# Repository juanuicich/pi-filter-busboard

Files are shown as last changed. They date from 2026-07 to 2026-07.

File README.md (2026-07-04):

# Low-Noise Eurorack Busboard (37cm)

An open-source, high-integrity power distribution busboard for Eurorack modular synthesizer systems. It features aggressive passive filtering designed specifically to clean up the switching and regulation ripple from standard industrial switched-mode power supplies (such as the Mean Well LRS-75-12).

## Features

- **37cm Long Layout:** Optimized for physical accessibility across 84hp cases without needing to uninstall central modules to change power cables.
- **Third-Order CLC Pi-Filter:** Achieves ~35dB of noise attenuation at 1kHz, eliminating audible regulation ripple and high-frequency switching hash (65kHz+).
- **Optional +5V Sub-System:** Includes an unpopulated TO-220 footprint compatible with high-efficiency switching buck regulators (e.g., Murata OKI-78SR-5) to drive 5V-enabled IDC headers locally.
- **LED Rail Indicators:** Post-filter diagnostic LEDs immediately confirm active voltage delivery to the distribution rail.

## Filter & Power Specifications

- **Input Terminals:** 3-pin screw terminal block (5.08mm pitch, Phoenix Contact standard).
- **Maximum Current Load:** 2A - 2.5A continuous per board.
- **Input Capacitors ($C_{in}$):** 220µF / 25V+ Low-ESR Electrolytic ($\le$ 0.1Ω impedance at 100kHz).
- **Series Inductors ($L$):** 330µH Toroidal Chokes ($\ge$ 3A rated, low DCR).
- **Output Capacitors ($C_{out}$):** 4700µF / 25V Low-ESR Electrolytic ($\le$ 0.03Ω impedance at 100kHz).

## Critical Assembly & Solder Notes

⚠️ **WARNING: REVERSE POLARITY HAZARD**
Electrolytic capacitors are polarized. On the **-12V rail**, Ground (0V) is the more positive potential. You **MUST** solder the positive lead (+) of the -12V capacitors directly to the Ground plane, and the negative lead (-) to the -12V trace. Installing them backward will cause the capacitors to burst violently upon power-up.

- **Thermal Reliefs:** Ensure your KiCad zone properties retain thermal relief spokes for through-hole pads, otherwise the massive output capacitors and ground planes will sink all the heat from your soldering iron.
- **Mechanical Security:** Because the 4700µF output capacitors carry significant mass, it is recommended to apply a small dab of non-conductive electronics-grade silicone or hot glue between the base of the capacitor capacitor body and the PCB after soldering to relieve trace stress during case transit.

## License

This project is open-source hardware. Feel free to modify, build, or manufacture your own variants.

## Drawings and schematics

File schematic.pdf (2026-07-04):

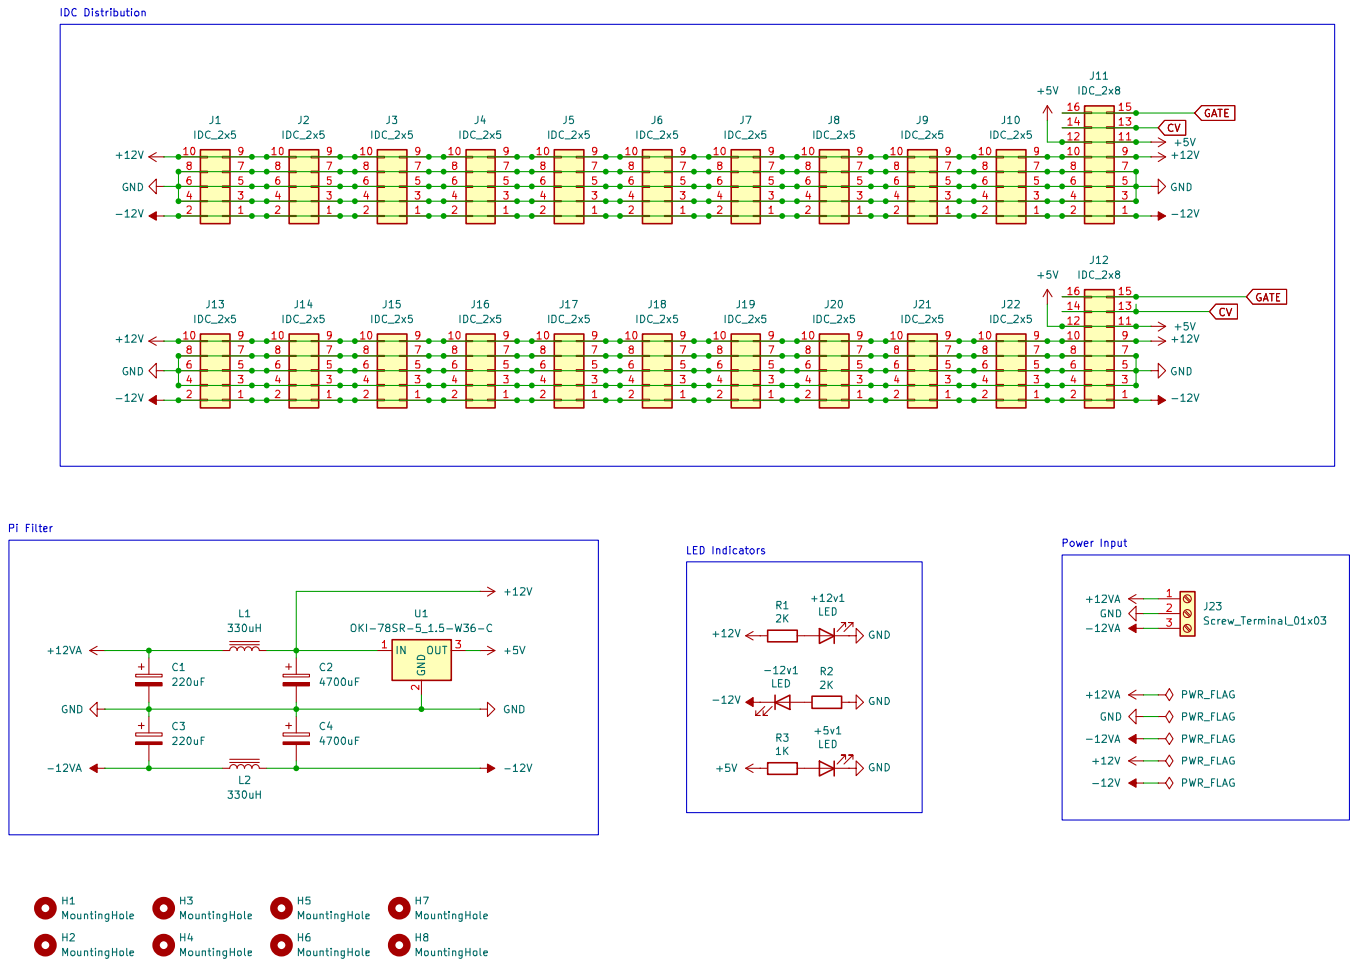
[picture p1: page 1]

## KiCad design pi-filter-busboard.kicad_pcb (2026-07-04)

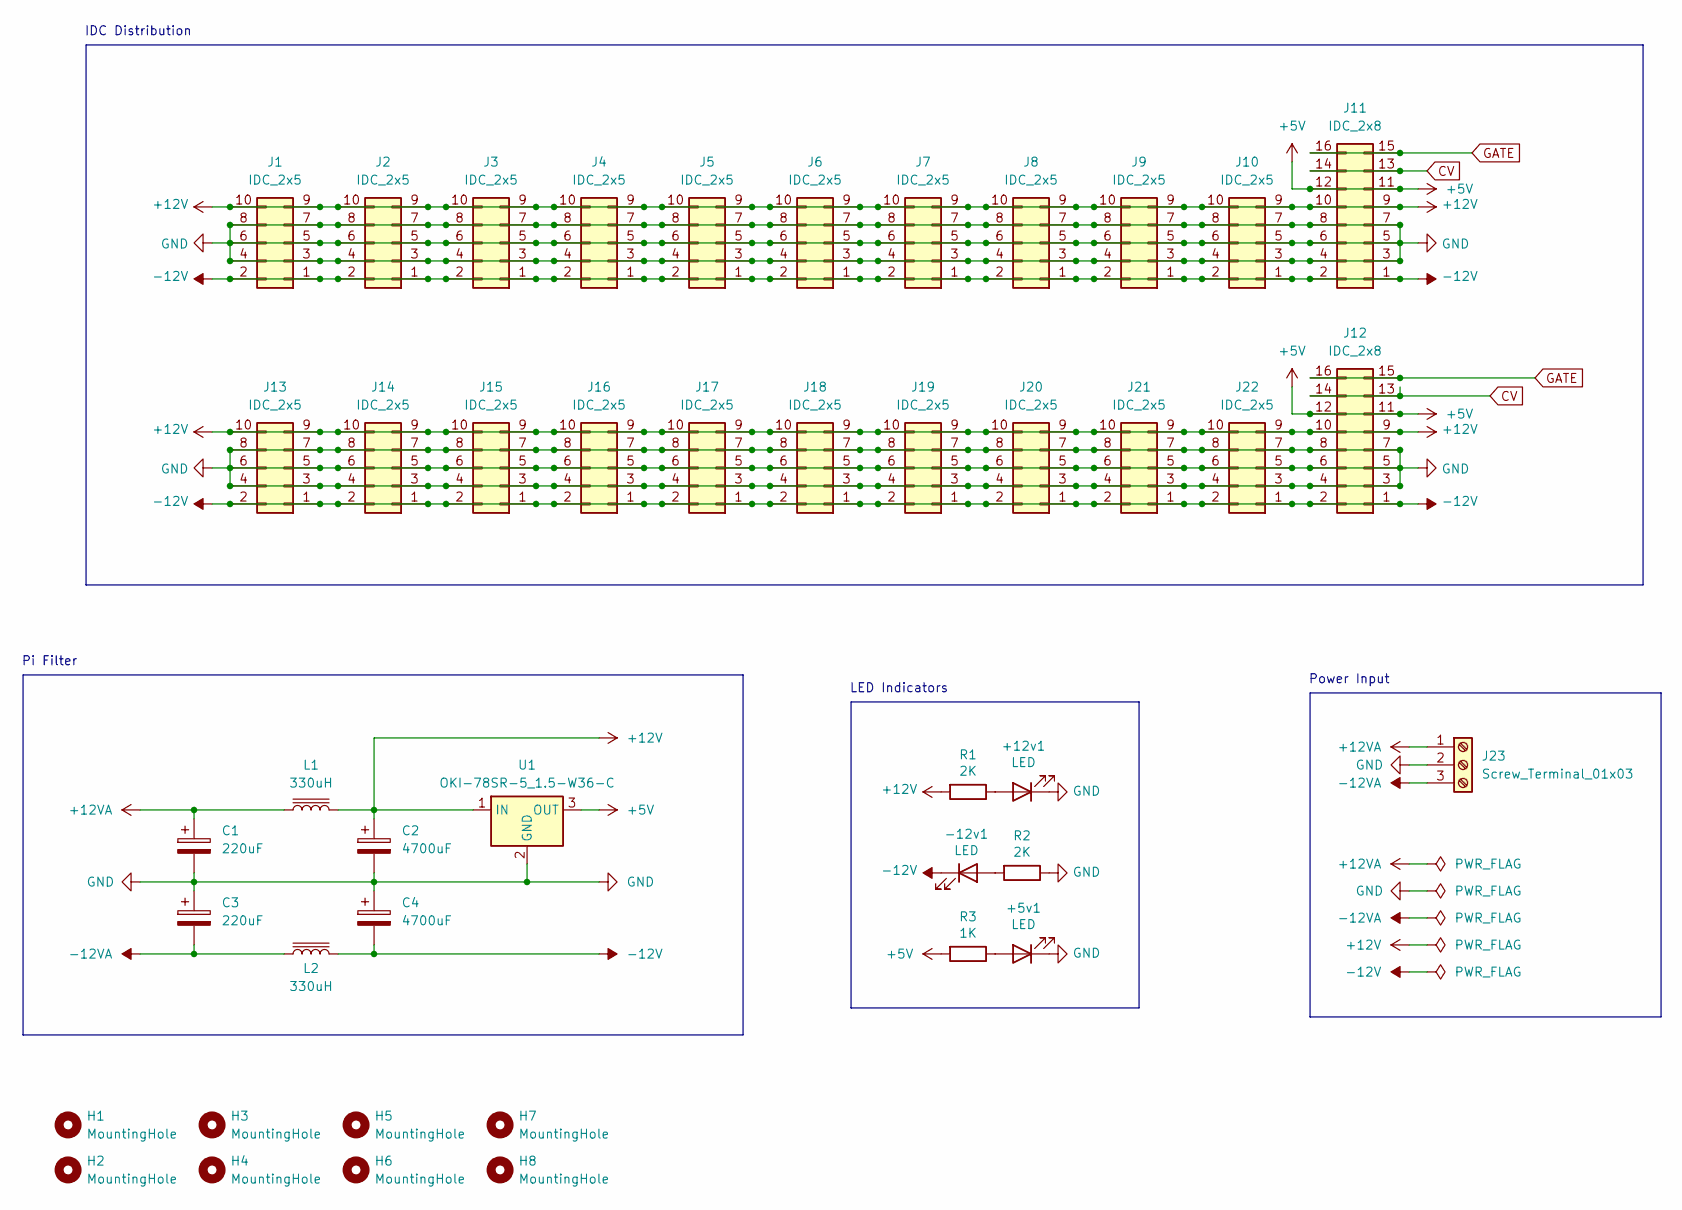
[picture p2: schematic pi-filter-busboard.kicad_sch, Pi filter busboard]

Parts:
+5v1, +12v1: LED; LED_D3.0mm
-12v1: LED; LED_D3.0mm
C1, C3: 220uF; CP_Radial_D8.0mm_P3.50mm
C2, C4: 4700uF; CP_Radial_D16.0mm_P7.50mm
H1, H2, H3, H4, H5, H6, H7, H8: MountingHole; MountingHole_3.2mm_M3
J1, J2, J3, J4, J5, J6, J7, J8, J9, J10, J13, J14, J15, J16, J17, J18, J19, J20, J21, J22: IDC_2x5; IDC-Header_2x05_P2.54mm_Vertical
J11, J12: IDC_2x8; IDC-Header_2x08_P2.54mm_Vertical
J23: Screw_Terminal_01x03; TerminalBlock_RND_205-00002_1x03_P5.00mm_Horizontal
L1, L2: 330uH; L_Toroid_Vertical_L21.6mm_W9.1mm_P8.40mm_Bourns_5700
R1, R2: 2K; R_Axial_DIN0207_L6.3mm_D2.5mm_P7.62mm_Horizontal
R3: 1K; R_Axial_DIN0207_L6.3mm_D2.5mm_P7.62mm_Horizontal
U1: OKI-78SR-5_1.5-W36-C; Converter_DCDC_Murata_OKI-78SR_Vertical

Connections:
+5V: J11.11, J11.12, J12.11, J12.12, R3.2, U1.3 (OUT)
+12V: C2.1, J1.9, J1.10, J2.9, J2.10, J3.9, J3.10, J4.9, J4.10, J5.9, J5.10, J6.9, J6.10, J7.9, J7.10, J8.9, J8.10, J9.9, J9.10, J10.9, J10.10, J11.9, J11.10, J12.9, J12.10, J13.9, J13.10, J14.9, J14.10, J15.9, J15.10, J16.9, J16.10, J17.9, J17.10, J18.9, J18.10, J19.9, J19.10, J20.9, J20.10, J21.9, J21.10, J22.9, J22.10, L1.2, R1.2, U1.1 (IN)
+12VA: C1.1, J23.1, L1.1
-12V: -12v1.1 (K), C4.2, J1.1, J1.2, J2.1, J2.2, J3.1, J3.2, J4.1, J4.2, J5.1, J5.2, J6.1, J6.2, J7.1, J7.2, J8.1, J8.2, J9.1, J9.2, J10.1, J10.2, J11.1, J11.2, J12.1, J12.2, J13.1, J13.2, J14.1, J14.2, J15.1, J15.2, J16.1, J16.2, J17.1, J17.2, J18.1, J18.2, J19.1, J19.2, J20.1, J20.2, J21.1, J21.2, J22.1, J22.2, L2.2; also elsewhere on the board
-12VA: C3.2, J23.3, L2.1
CV: J11.13, J11.14, J12.13, J12.14
GATE: J11.15, J11.16, J12.15, J12.16
GND: +5v1.1 (K), +12v1.1 (K), C1.2, C2.2, C3.1, C4.1, J1.3, J1.4, J1.5, J1.6, J1.7, J1.8, J2.3, J2.4, J2.5, J2.6, J2.7, J2.8, J3.3, J3.4, J3.5, J3.6, J3.7, J3.8, J4.3, J4.4, J4.5, J4.6, J4.7, J4.8, J5.3, J5.4, J5.5, J5.6, J5.7, J5.8, J6.3, J6.4, J6.5, J6.6, J6.7, J6.8, J7.3, J7.4, J7.5, J7.6, J7.7, J7.8, J8.3, J8.4, J8.5, J8.6, J8.7, J8.8, J9.3, J9.4, J9.5, J9.6, J9.7, J9.8, J10.3, J10.4, J10.5, J10.6, J10.7, J10.8, J11.3, J11.4, J11.5, J11.6, J11.7, J11.8, J12.3, J12.4, J12.5, J12.6, J12.7, J12.8, J13.3, J13.4, J13.5, J13.6, J13.7, J13.8, J14.3, J14.4, J14.5, J14.6, J14.7, J14.8, J15.3, J15.4, J15.5, J15.6, J15.7, J15.8, J16.3, J16.4, J16.5, J16.6, J16.7, J16.8, J17.3, J17.4, J17.5, J17.6, J17.7, J17.8, J18.3, J18.4, J18.5, J18.6, J18.7, J18.8, J19.3, J19.4, J19.5, J19.6, J19.7, J19.8, J20.3, J20.4, J20.5, J20.6, J20.7, J20.8, J21.3, J21.4, J21.5, J21.6, J21.7, J21.8, J22.3, J22.4, J22.5, J22.6, J22.7, J22.8, J23.2, R2.1, U1.2 (GND); also elsewhere on the board
unnamed 8: +5v1.2 (A), R3.1; also elsewhere on the board
unnamed 9: +12v1.2 (A), R1.1; also elsewhere on the board
unnamed 10: -12v1.2 (A), R2.2; also elsewhere on the board

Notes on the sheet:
LED Indicators
Power Input
IDC Distribution
Pi Filter

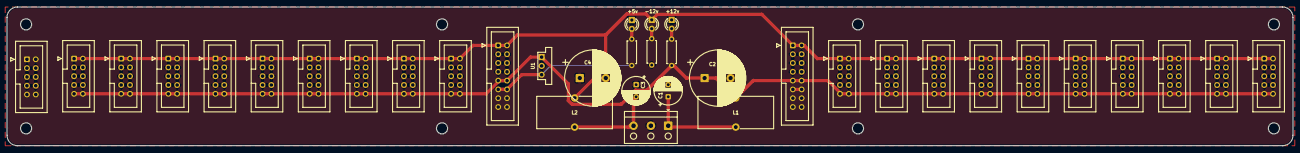
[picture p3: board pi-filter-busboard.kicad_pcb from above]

Board: 2 copper layers, 371.0 x 40.0 mm, 44 parts (0 on the bottom side), 11 nets.

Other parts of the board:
+5v, +12v: LED; LED_D3.0mm
-12v: LED; LED_D3.0mm

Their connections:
-12V: -12v.1 (K); also elsewhere on the board
GND: +5v.1 (K), +12v.1 (K); also elsewhere on the board
unnamed 8: +5v.2 (A); also elsewhere on the board
unnamed 9: +12v.2 (A); also elsewhere on the board
unnamed 10: -12v.2 (A); also elsewhere on the board

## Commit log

2026-07-04 Initial commit: pi-filter busboard KiCad project
    [pi-filter-busboard.kicad_pcb, pi-filter-busboard.kicad_sch]
2026-07-04 Update PCB layout
    [pi-filter-busboard.kicad_pcb]
